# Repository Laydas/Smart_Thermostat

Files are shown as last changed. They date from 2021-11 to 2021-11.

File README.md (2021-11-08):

# Smart Thermostat 

COMP444 Final Project - ESP32 Smart Thermostat

## Project Overview

- WT32-SC01 ESP32 development module
  - Base station
  - Attached DHT22 for temp/humidity
  - Controls signal to home furnace
  - Programmable heating schedule
  - Manual override from screen
  - Receive temperatures from room modules
  - Connect to HA (Home Assistant) using the ESP Home integration
- ESP8266/ESP32 Modules
  - Records temp/humidity in each room
  - Sends metrics to HA or Base

## Required Setup
- Clone sowbug/Adafruit_FT6206_Library to ArduinoIDE libraries
- Modify TFT_eSPI/User_Setup_Select.h to point to the WT32-SC01 board

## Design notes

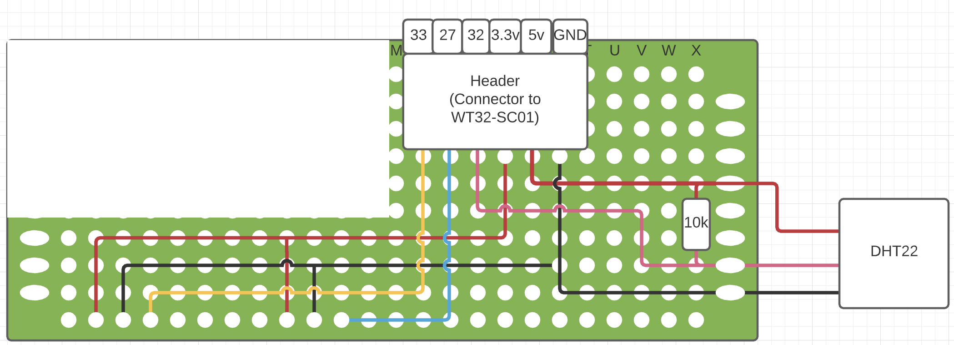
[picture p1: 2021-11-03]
Circuit_Layout/PCB_Layout.png

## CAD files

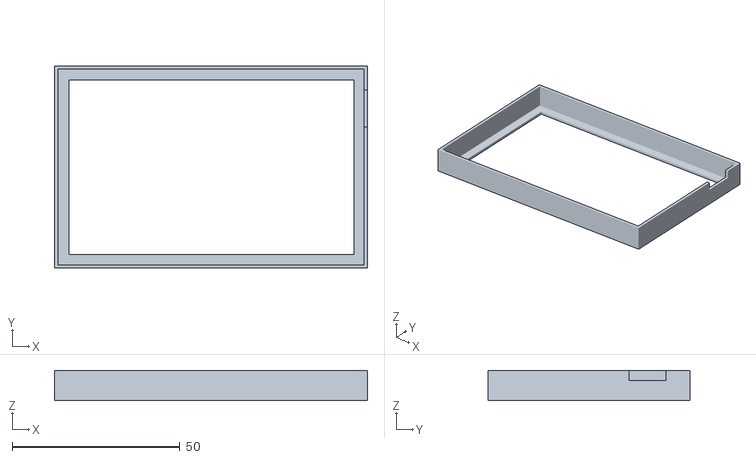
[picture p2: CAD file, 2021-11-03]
3D_Print_Files/Thermostat_Top.stl
93.2 x 60.3 x 9.00

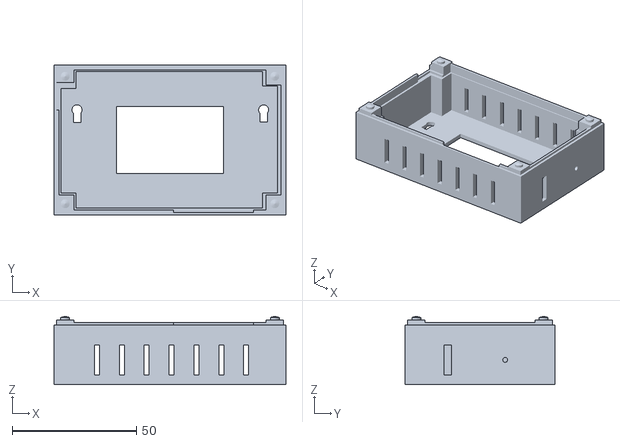
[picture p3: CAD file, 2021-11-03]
3D_Print_Files/Thermostat_Super_Tall_Base.stl
93.2 x 60.3 x 27.5

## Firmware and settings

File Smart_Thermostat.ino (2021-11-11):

/*

Iain Letourneau

ESP32 on the WT32-SC01 development board
Smart Thermostat

Uses an internally stored schedule to determine what temperature/humidity the house
should be. Has a DHT22 connected on the outside of the enclosure that feeds temp info
back to the board.

Controls a furnace by sending a command to turn on or off using PID control to avoid
overshooting the heating. Also controls the humidifier on the furnace.
 
*/
#include "DHT.h"
#include "WiFi.h"
#include <Adafruit_FT6206.h>

#include "Draw.h"
#include "Thermostat.h"
#include "secrets.h"

#define DHTPIN 32
#define HEATPIN 33
#define HUMDPIN 27
#define DHTTYPE DHT22

DHT dht(DHTPIN, DHTTYPE);
Adafruit_FT6206 ts = Adafruit_FT6206();

// Keep all the intervals in one object
struct intervals {
  unsigned long prev = 0;
  unsigned long prev_wifi = 0;
  unsigned long prev_heat = 0;
  unsigned long intv = 2000;
  unsigned long intv_wifi = 30000;
  unsigned long intv_heat = 120000;
} interval;

Thermostat thermostat = Thermostat(HEATPIN, HUMDPIN);
Draw draw = Draw();

/**
 * @brief Holds the current (or old) temperature. Used to compare against incoming
 * sensor readings and used to pass temps to other class methods
 * 
 */
struct old{
  float temp;
  float humd;
} old;

// Create a button object using the 4 corner coordinates
struct Button {
  int x, y, x2, y2;
  Button(int x, int x2, int y, int y2):x(x), x2(x2), y(y), y2(y2){}
};

// Define where each button is going to go on the screen
struct Layout {
  Button next_dow = Button(170, 210, 20, 80);
  Button prev_dow = Button(30, 70, 20, 80);
  Button menu_bar = Button(380, 480, 80, 320);
  Button menu_rooms = Button(380, 480, 80, 160);
  Button menu_sched = Button(380, 480, 160, 240);
  Button menu_setting = Button(380,480, 240, 320);
  Button hold = Button(0, 80, 130, 190);
  Button up_hold = Button(80, 230, 110, 215);
  Button down_hold = Button(80, 230, 215, 320);
  Button up_humd = Button(230, 380, 110, 215);
  Button down_humd = Button(230, 380, 215, 320);
} Layout;

char* nav[4] = {"Main","Rooms","Schedule","Settings"};

// Internet and NTP information
const char* ssid = SSID_NAME;
const char* password = SSID_PASS;
const char* ntpServer = "pool.ntp.org";
const long gmtOffset_sec = -25200;
const int daylightOffset_sec = 3600;

int nav_current = 0;


void setup() {
  // Initialization of all the classes/objects needed
  Serial.begin(115200);
  configTime(gmtOffset_sec, daylightOffset_sec, ntpServer);
  dht.begin();
  initWiFi();
  thermostat.begin();

  if (!ts.begin(18, 19, 40)) {
    Serial.println("Couldn't start touchscreen controller");
    while (true);
  }

  draw.begin();
  // Draw the main landing screen
  draw.main(old.temp, old.humd, thermostat.getGoalTemp(), thermostat.getGoalHumd(), thermostat.getHold());
}

void loop() {
  // Update the onboard temp/humidity every 2 seconds. This might be a bit aggressive.
  unsigned long current = millis();
  if(current - interval.prev >= interval.intv){
    interval.prev = current;
    // Update the sensor readings
    old.temp = getDHTTemp(old.temp, nav[nav_current]);
    old.humd = getDHTHum(old.humd, nav[nav_current]);
    // Draw the date string at the top of the screen
    draw.time();

    // If the time has moved into a new scheduled slot then draw the goal temp again
    if(thermostat.checkSchedule()){
      draw.goalTemp(thermostat.getHold(), thermostat.getGoalTemp());
    }

    // Turn heating/humidity on/off every 5 minutes ( to avoid constantly turning on furnace )
    if(current - interval.prev_heat >= interval.intv_heat){
      thermostat.keepTemperature(old.temp);
      thermostat.keepHumidity(old.humd);
      interval.prev_heat = current;
    }
    
    // Attempt to reconnect to wifi if disconnected
    checkWifi();
    if((WiFi.status() != WL_CONNECTED) && (current - interval.prev_wifi >= interval.intv_wifi)){
      WiFi.disconnect();
      WiFi.reconnect();
      interval.prev_wifi = current;
    }
    interval.prev = current;
  }
    
  // Restart loop if the screen hasn't been touched
  if (! ts.touched()) {
    return;
  }

  handleTouch(ts.getPoint(), nav[nav_current]);

  delay(250); // Delay to reduce loop rate (reduces flicker caused by aliasing with TFT screen refresh rate)
}

/**
 * @brief Handle input from screen
 * 
 * @param p 
 * @param screen 
 */
void handleTouch(TS_Point p, char* screen){
  int y = p.x;
  int x = map(p.y, 0, 480, 480, 0);

  // Handle all buttons that would appear on the main screen
  if (screen == "Main"){
    // Check to see if the touch was inside the menu bar (for now it's the only buttons on main anyways)
    if(isButton(x, y, Layout.menu_bar)){
      if(isButton(x, y, Layout.menu_rooms)){
        nav_current = 1;
        draw.rooms();
      } else if(isButton(x, y, Layout.menu_sched)){
        nav_current = 2;
        String slots[10];
        thermostat.daySlots(slots);
        draw.schedule(slots, thermostat.getShortDow());
      } else if(isButton(x, y, Layout.menu_setting)){
        nav_current = 3;
        draw.settings(thermostat.getHold(), thermostat.getHoldTemp(), thermostat.getGoalHumd());
      }
    }
  } else {
    // Check to see if the back button was pressed on the other screens
    if(isButton(x,y, Layout.menu_bar)){
      if(isButton(x, y, Layout.menu_rooms)){
        nav_current = 0;
        draw.main(old.temp, old.humd, thermostat.getGoalTemp(), thermostat.getGoalHumd(), thermostat.getHold());
      }
    }
  }

  // Settings has most of the buttons right now, this handles the control of holding a temp or setting
  // the current humidity goal
  if(screen == "Settings"){
    boolean touched_button = false;
    if(isButton(x, y, Layout.up_humd)){
      thermostat.setTargetHumidity(thermostat.getGoalHumd() + 1);
      touched_button = true;
    }
    if(isButton(x, y, Layout.down_humd)){
      thermostat.setTargetHumidity(thermostat.getGoalHumd() - 1);
      touched_button = true;
    }
    if(isButton(x, y, Layout.up_hold)){
      thermostat.setHoldTemp(thermostat.getHoldTemp() + 0.5f);
      touched_button = true;
    }
    if(isButton(x, y, Layout.down_hold)){
      thermostat.setHoldTemp(thermostat.getHoldTemp() - 0.5f);
      touched_button = true;
    }
    if(isButton(x, y, Layout.hold)){
      thermostat.toggleHold();
      touched_button = true;
    }
    // Only redraw the screen when a change has been made/button touched
    if(touched_button) 
      draw.settings(thermostat.getHold(), thermostat.getHoldTemp(), thermostat.getGoalHumd());
  }

  // Navigate through to view the weeks schedule
  if(screen == "Schedule"){
    if(isButton(x, y, Layout.prev_dow)){
      thermostat.prevDisplayDay();
      String slots[10];
      thermostat.daySlots(slots);
      draw.schedule(slots, thermostat.getShortDow());
    }
    if (isButton(x, y, Layout.next_dow)){
      thermostat.nextDisplayDay();
      String slots[10];
      thermostat.daySlots(slots);
      draw.schedule(slots, thermostat.getShortDow());
    }
  }
}

/**
 * @brief Checks to see if the touched coordinates are inside the button
 * 
 * @param x 
 * @param y 
 * @param button 
 * @return boolean 
 */
boolean isButton(int &x, int &y, Button &button){
  if((x > button.x && x < button.x2) && (y > button.y && y < button.y2))
    return true;
  else
    return false;
}

// Update the screen with the temperature
float getDHTTemp(float old_temp, char* screen){
  float temp = dht.readTemperature();
  if (temp != old_temp && screen == "Main"){
    draw.dhtTemp(temp);
  }
  return temp;
}

// Update the screen with the humidity
float getDHTHum(float old_humd, char* screen){
  float humd = dht.readHumidity();
  if (humd != old_humd && screen == "Main"){
    draw.dhtHumd(humd);
  }
  return humd;
}

// Turn on the wifi and connect
void initWiFi(){
  WiFi.mode(WIFI_STA);
  WiFi.begin(ssid, password);
  while(WiFi.status() != WL_CONNECTED) {
    delay(500);
  }
}

/**
 * @brief Check the strength of the wifi and call the draw.wifi with the current strength
 * 
 */
void checkWifi(){
  if(WiFi.status() != WL_CONNECTED){
    draw.wifi(455,35,0);
    return;
  }
  int strength = WiFi.RSSI();
  if(strength > -50){
    draw.wifi(455, 35, 3);
  } else if(strength > -70){
    draw.wifi(455, 35, 2);
  } else {
    draw.wifi(455, 35, 1);
  }
}

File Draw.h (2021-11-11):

#ifndef DRAW_H
#define DRAW_H

#include <TFT_eSPI.h> 
#include <SPI.h>
#include "Free_Fonts.h"
#include "time.h"

#include "Home_Icon.h"
#include "Cal_Icon.h"
#include "Gear_Icon.h"
#define DEG2RAD 0.0174532925
#define PENRADIUS 2

/**
 * @brief This class has preconfigured drawing methods for a 480x320 pixel
 * tft screen, in this case the WT32-SC01 development board.
 * 
 */
class Draw {
  private:
    TFT_eSPI tft = TFT_eSPI();
    TFT_eSprite img = TFT_eSprite(&tft);
    const uint16_t *menu[3] = {Home_Icon, Cal_Icon, Gear_Icon};

  public:
    void begin();
    
    // Navigational
    void main(float temp, float humd, float goal_temp, float goal_humd, boolean holding);
    void rooms();
    void schedule(String slots[], String short_dow);
    void settings(boolean hold, float hold_temp, float goal_humd);

    // Helper functions
    void tempHeaders();
    void back(TFT_eSprite &img);
    void wifi(int x, int y, int strength);
    void fillArc(int x, int y, int start_angle, int seg_count, int rx, int ry, int w, unsigned int colour);
    void time();

    // Temperature Sensor
    void dhtHumd(float humd);
    void dhtTemp(float temp);
    void goalHumd(float humd);
    void goalTemp(boolean holding, float temp);
    
    // Fonts
    void mainFont(TFT_eSprite& img);
    void secondFont(TFT_eSprite& img);
    void headerFont(TFT_eSprite& img);
    void tableFont(TFT_eSprite& img);
};

/**
 * @brief Pins 18/19 are SDA/SCL for touch sensor on this device
 * 40 is a touch threshold
 * 
 */
void Draw::begin(){
  tft.init();
  tft.fillScreen(TFT_BLACK);
  tft.setRotation(3);
  pinMode(TFT_BL, OUTPUT);
  digitalWrite(TFT_BL, 128);
}

/**
 * @brief Draw out the main landing screen with navigation to all
 * other screens with thermostat functions
 * 
 * @param temp 
 * @param humd 
 * @param goal_temp 
 * @param goal_humd 
 * @param holding
 */
void Draw::main(float temp, float humd, float goal_temp, float goal_humd, boolean holding){
  img.createSprite(480, 280);
  img.fillScreen(TFT_BLACK);
  img.pushSprite(0, 40);
  img.deleteSprite();
  for (int i = 0; i < 3; i++){
    tft.pushImage(380, (i+1) * 80, 100, 80, menu[i]);
  }
  tempHeaders();
  dhtTemp(temp);
  dhtHumd(humd);
  goalTemp(holding, goal_temp);
  goalHumd(goal_humd);
}

/**
 * @brief This will be a list of sensors in the house and their respective output
 * 
 */
void Draw::rooms(){
  img.createSprite(480, 280);
  img.fillRect(0, 0, 480, 280, TFT_BLACK);
  //img.pushSprite(0, 40);
  //img.deleteSprite();
  //img.createSprite(380, 260);
  //img.fillRect(0, 0, 380, 260, TFT_BLACK);
  mainFont(img);
  img.setTextDatum(MC_DATUM);
  img.drawString("Rooms!", 190, 130);
  back(img);
  img.pushSprite(0, 40);
  img.deleteSprite();
}

/**
 * @brief Allows you to view the schedule for the currently select day
 * 
 * @param day_slots 
 * @param short_dow 
 */
void Draw::schedule(String slots[], String short_dow){
  img.createSprite(480, 280);
  img.fillRect(0,0,480,280,TFT_BLACK);
  mainFont(img);
  img.fillTriangle(40,20,60,0,60,40, TFT_WHITE);
  img.fillTriangle(200,20,180,0,180,40, TFT_WHITE);
  img.setTextDatum(MC_DATUM);
  img.drawString(short_dow, 120, 20);
  img.setTextDatum(ML_DATUM);
  tableFont(img);
  for(int i = 0; i < 10; i++){
    if(slots[i] == "") continue;
    img.drawString(slots[i], 20, 80+(i*40), GFXFF);
    img.drawCircle(285,70+(i*40),3,TFT_WHITE);
  }
  back(img);
  img.pushSprite(0,40);
  img.deleteSprite();
}

/**
 * @brief Displays the target humidity
 * 
 * @param goal_humd current target humidity
 */
void Draw::settings(boolean hold, float hold_temp, float goal_humd){
  img.createSprite(480, 280);
  img.fillRect(0,0,480,280,TFT_BLACK);
  // Write out headers
  secondFont(img);
  img.setTextDatum(MC_DATUM);
  img.drawString("Hold", 40, 50);
  img.drawString("Hold Temp", 155, 50);
  img.drawString("Humidity", 305, 50);
  
  // Draw out triangles and buttons
  mainFont(img);
  if(hold){
    img.drawString("ON", 40, 120);
  } else {
    img.drawString("OFF", 40, 120);
  }
  img.drawRoundRect(10, 90, 60, 60, 5, TFT_WHITE);
  img.fillTriangle(155,90,185,120,125,120, TFT_WHITE);
  img.fillTriangle(155,240,185,210,125,210, TFT_WHITE);
  img.fillTriangle(305,90,335,120,275,120, TFT_WHITE);
  img.fillTriangle(305,240,335,210,275,210, TFT_WHITE);
  img.drawString(String(hold_temp), 155, 160);
  String temp_str = String((int)goal_humd);
  temp_str += "%";
  img.drawString(temp_str, 305, 160);
  back(img);
  img.pushSprite(0,40);
  img.deleteSprite();
  
}

/**
 * @brief Draws out the current/target column headers
 * 
 */
void Draw::tempHeaders(){
  img.createSprite(360,30);
  secondFont(img);
  img.setTextDatum(ML_DATUM);
  img.drawString("current",20,15, GFXFF);
  img.drawString("target", 200, 15, GFXFF);
  img.pushSprite(0,150);
  img.deleteSprite();
}

/**
 * @brief Draws a back arrow, used in nested navigational screens
 * 
 */
void Draw::back(TFT_eSprite &img){
  //img.createSprite(80, 80);
  int start_x = 410;
  int start_y = 80;
  for(int i = 0; i < 25; i++){
    img.fillCircle(start_x + i, start_y - i, PENRADIUS, TFT_WHITE);
  }
  
  for(int i = 0; i < 25; i++){
    img.fillCircle(start_x + i, start_y + i, PENRADIUS, TFT_WHITE);
  }

  for(int i = 0; i < 50; i++){
    img.fillCircle( start_x + i, start_y, PENRADIUS, TFT_WHITE);
  }
}

/**
 * @brief draws the wifi logo according to strength
 * 
 * @param x center of wifi logo
 * @param y center of wifi logo
 * @param strength 0-3
 */
void Draw::wifi(int x, int y, int strength){
  uint16_t str_sig[3] = {0x39E7,0x39E7,0x39E7};
  for (int i = 0; i < strength; i++){
    str_sig[i] = TFT_WHITE; 
  }
  fillArc(x, y, 310, 17, 25, 30, 4, str_sig[2]);
  fillArc(x, y+5, 315, 15, 18, 25, 4, str_sig[1]);
  tft.fillCircle(x-1, y-7, 4, str_sig[0]);
}
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

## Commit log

2021-10-11 Initial commit with demo code for device
2021-10-13 Added fonts and fixed rotation
    [Smart_Thermostat.ino]
2021-10-13 Added gear icon for settings
2021-10-29 Fixed up schedule screen
    [Smart_Thermostat.ino]
2021-10-29 Get target temp at power on configured
2021-10-30 Cleaned up main nav and fixed schedule error
    [Smart_Thermostat.ino]
2021-11-03 Included documentation files
    [Thermostat_Super_Tall_Base.stl, Thermostat_Top.stl]
2021-11-03 Cleaned up code and tested relays
2021-11-04 Fixed some logic errors, working again
    [Smart_Thermostat.ino, Thermostat.h]
2021-11-06 Added heating to thermostat class, cleaned up a bit
2021-11-09 Created struct for screen buttons
2021-11-10 checkSchedule now returns true if slot changed
2021-11-10 Fixed draw class, fixed refresh flicker
    [Draw.h, Smart_Thermostat.ino, Thermostat.h]
2021-11-10 Added hold temperature logic
2021-11-11 fixed humidity control errors
    [Draw.h, Smart_Thermostat.ino, Thermostat.h]
